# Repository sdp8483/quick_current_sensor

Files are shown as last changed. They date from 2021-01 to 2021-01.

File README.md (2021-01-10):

# Quick Current Sensor

This is a current sensor of various ranges for DC current measurements. The number one goal of this project was to make a set of current sensors only using what I have on hand, no buying anything. Also this has to be a simple design that gets the job done. It is not then best design and will not be the most accurate so it requires characterization before use. I suggest finding a better design with properly selected components, I suggest looking into the INA series of current sense amplifiers from TI that would make a better opamp to use then the old LM358. Again the only goal of this project is to use what I have already and not to waste time searching for the perfect components. Searching for the perfect components and design is what has stalled this project for years. That is just my way of defending the terrible design decisions made here and why you should look somewhere else for a current sensor.

### Calculations
[Google Sheets Link](https://docs.google.com/spreadsheets/d/1N8hUBOZxmFQPPFe9W_K_Z5sfmQMQ_LQjQ09W4D_ssm8/edit?usp=sharing)

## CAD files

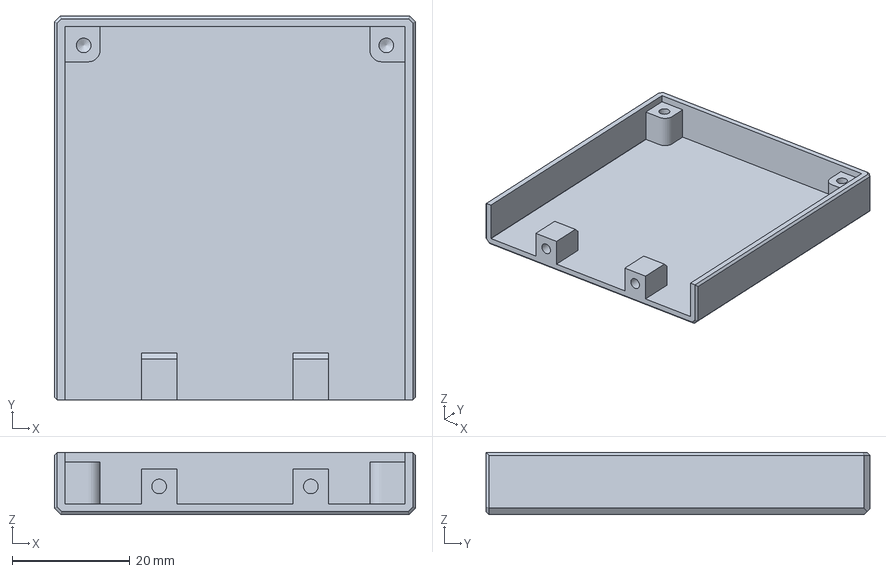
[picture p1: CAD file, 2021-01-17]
enclosure/bottom.amf
61.5 x 65.3 x 10.6 mm

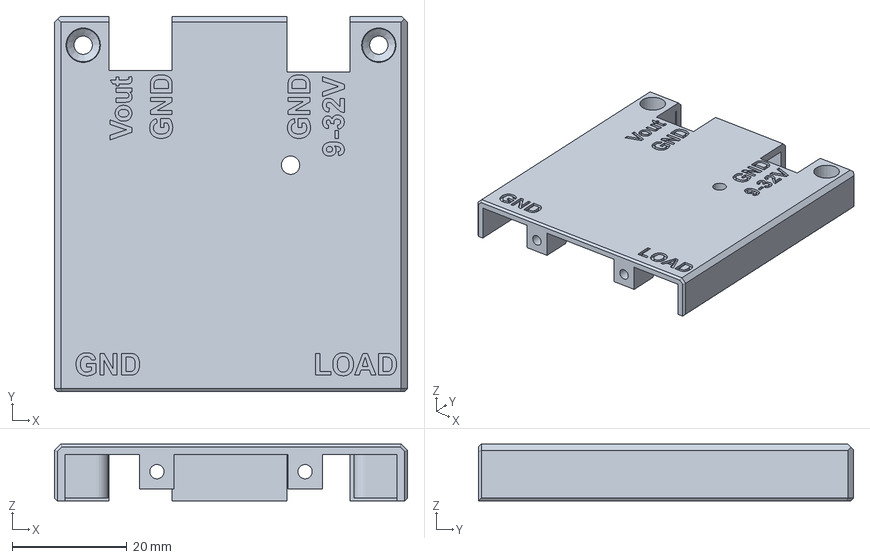
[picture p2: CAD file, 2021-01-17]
enclosure/top.amf
61.5 x 65.3 x 9.90 mm

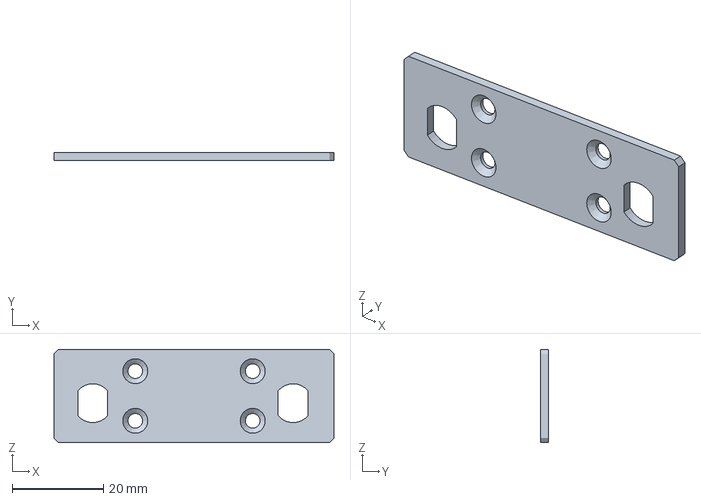
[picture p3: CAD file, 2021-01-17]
enclosure/pannel.amf
61.5 x 1.80 x 20.5 mm

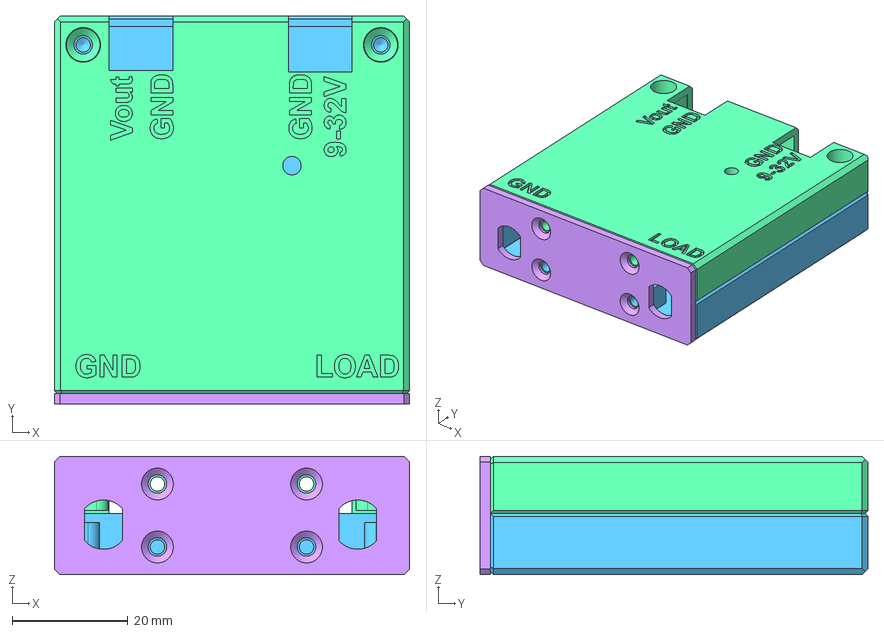
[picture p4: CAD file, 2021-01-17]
enclosure/qcs_enclosure.FCStd
61.5 x 67.1 x 20.5 mm
pannel
enclosure_bottom
enclosure_top

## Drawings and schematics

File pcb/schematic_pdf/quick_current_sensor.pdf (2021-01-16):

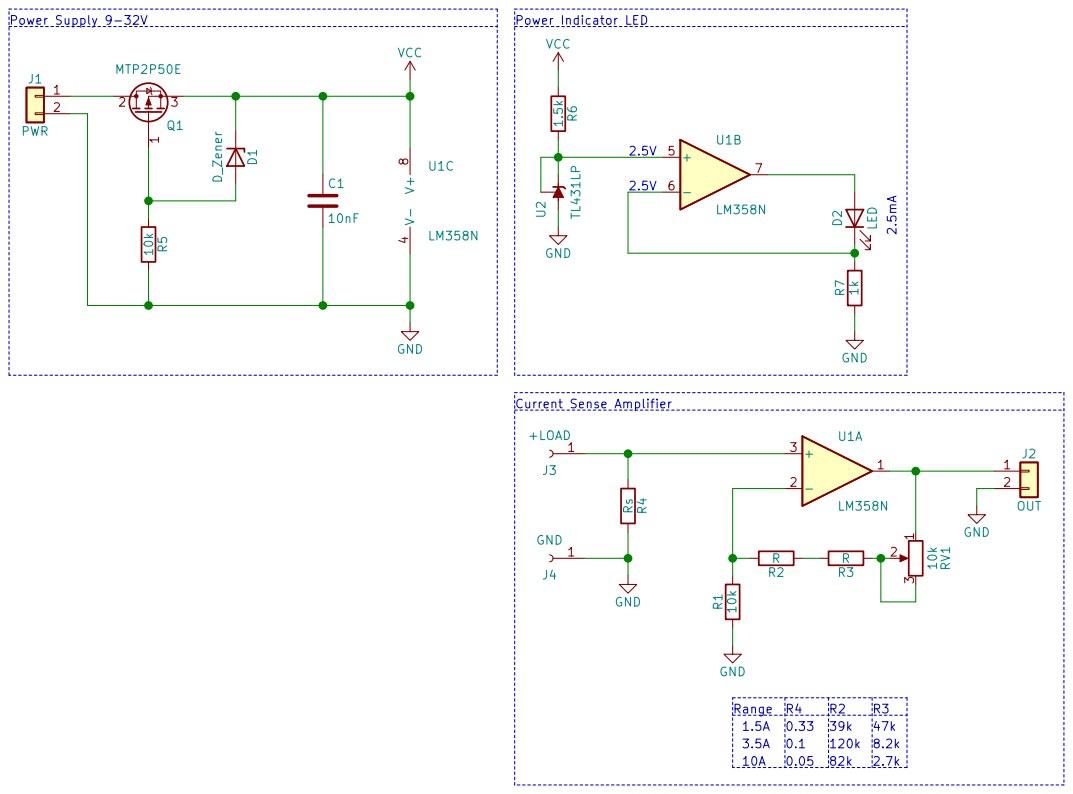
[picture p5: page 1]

R4 | 39k Range R2 | R3
1.5A 3.5A | 0.33 0.05 | 2.7k 8.2k 47k

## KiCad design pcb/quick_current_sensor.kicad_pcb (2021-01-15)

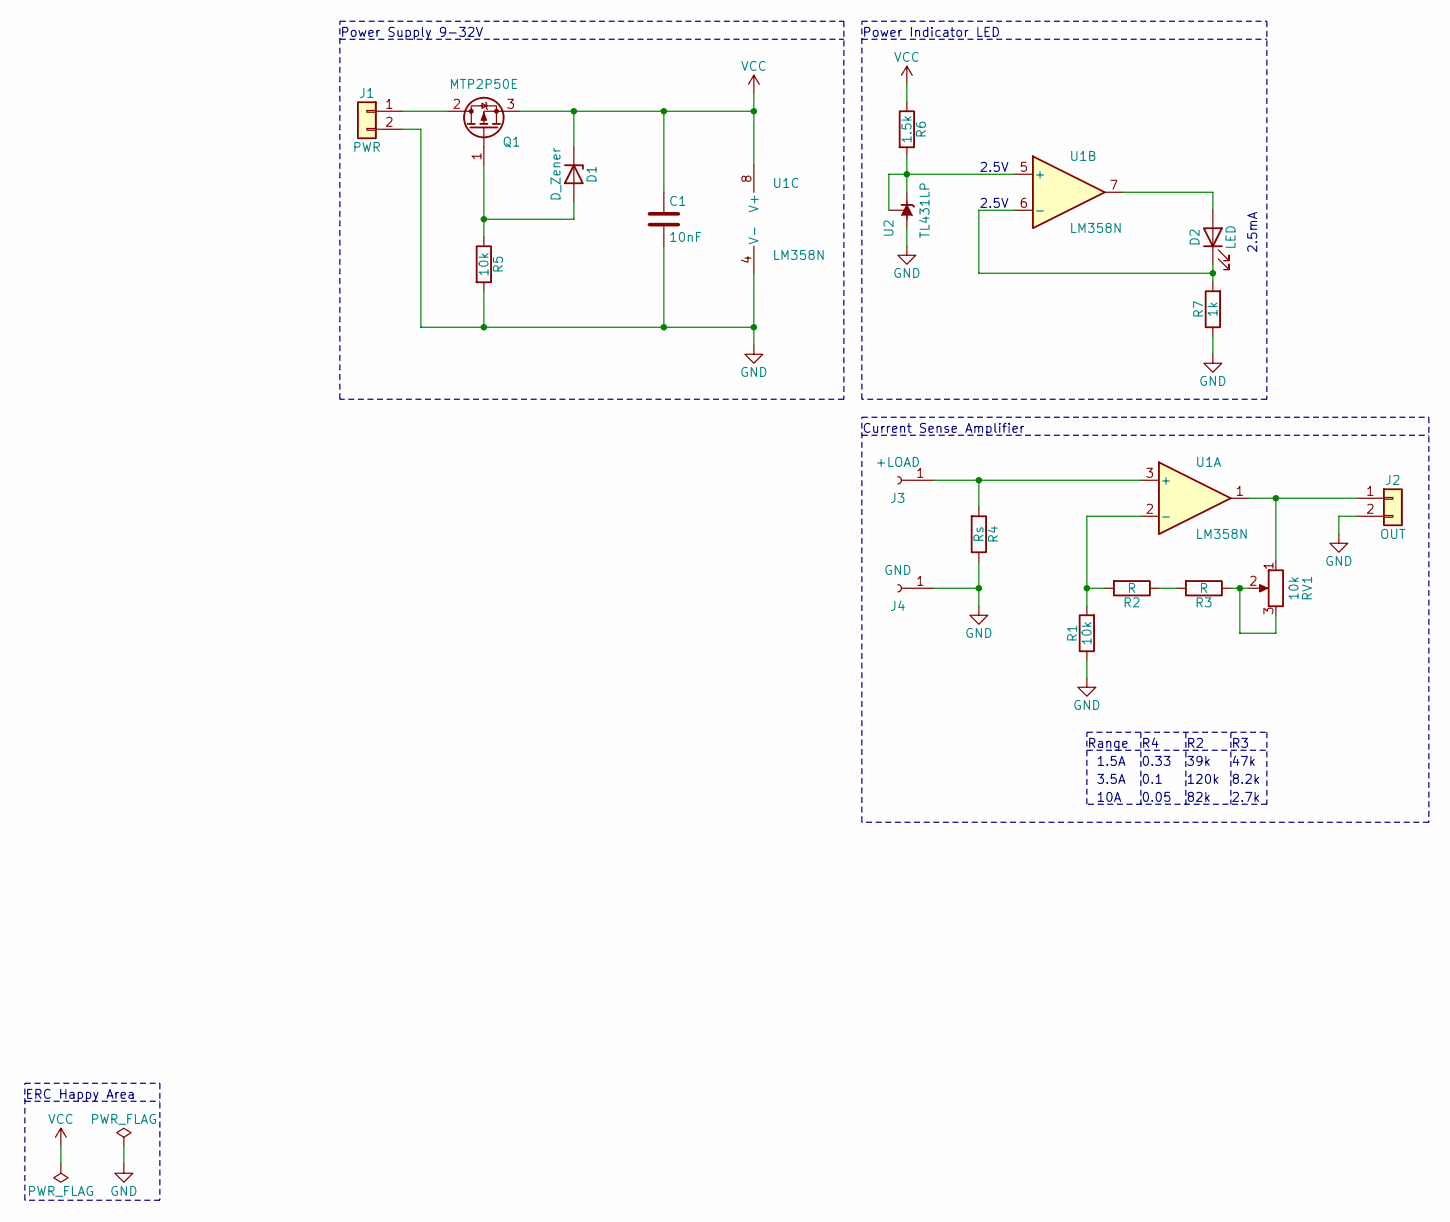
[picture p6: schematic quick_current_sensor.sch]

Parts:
C1: 10nF; C_0805_2012Metric_Pad1.18x1.45mm_HandSolder
D1: D_Zener; Nexperia_BZV55_SOD80C
D2: LED; LED_D3.0mm
J1: PWR; WJ127-5.0-2P
J2: OUT; WJ127-5.0-2P
J3: +LOAD; banana_edge_mount
J4: GND; banana_edge_mount
Q1: MTP2P50E; TO-220-3_Horizontal_TabUp
R1, R5: 10k; R_Axial_DIN0207_L6.3mm_D2.5mm_P10.16mm_Horizontal
R2, R3: R; R_Axial_DIN0207_L6.3mm_D2.5mm_P10.16mm_Horizontal
R4: Rs; RH-10
R6: 1.5k; R_Axial_DIN0207_L6.3mm_D2.5mm_P10.16mm_Horizontal
R7: 1k; R_Axial_DIN0207_L6.3mm_D2.5mm_P10.16mm_Horizontal
RV1: 10k; Potentiometer_Bourns_3006P_Horizontal
U1: LM358N; DIP-8_W7.62mm_LongPads
U2: TL431LP; TO-92_W4.0mm_StaggerEven_Horizontal_FlatSideDown

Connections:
GND: C1.2, J1.2, J2.2, J4.1, R1.1, R4.1, R5.2, R7.1, U1.4 (V-), U2.2 (A)
unnamed: D1.2 (A), Q1.1 (G), R5.1
unnamed: D2.1 (K), R7.2, U1.6 (-)
unnamed: D2.2 (A), U1.7
unnamed: J1.1, Q1.2 (D)
unnamed: J2.1, RV1.1, U1.1
unnamed: J3.1, R4.2, U1.3 (+)
unnamed: R1.2, R2.2, U1.2 (-)
unnamed: R2.1, R3.2
unnamed: R3.1, RV1.2, RV1.3
unnamed: R6.2, U1.5 (+), U2.1 (REF), U2.3 (K)
VCC: C1.1, D1.1 (K), Q1.3 (S), R6.1, U1.8 (V+)

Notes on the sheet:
Range
1.5A
3.5A
10A
0.33
0.1
0.05
39k
120k
82k
47k
8.2k
2.7k
2.5V
2.5mA
Power Supply 9-32V
Power Indicator LED
Current Sense Amplifier
ERC Happy Area

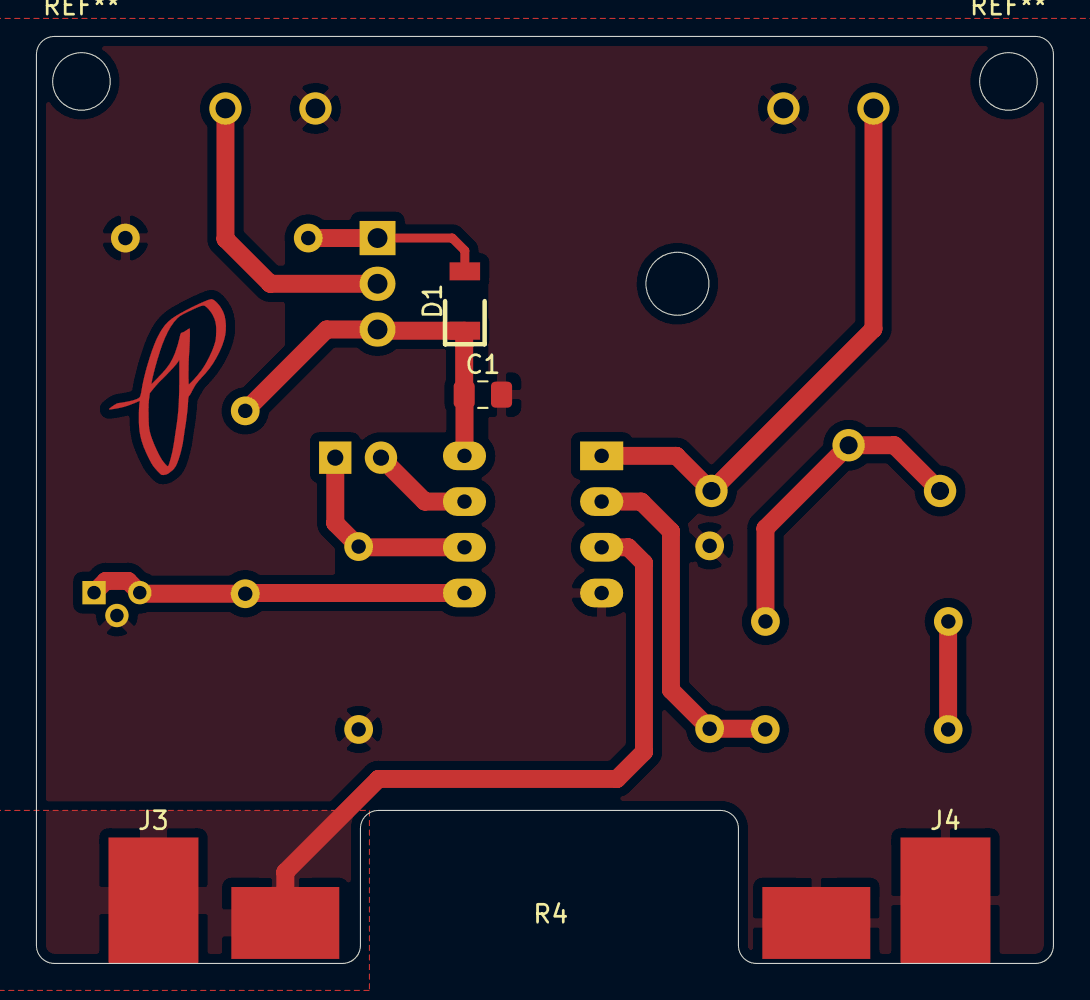
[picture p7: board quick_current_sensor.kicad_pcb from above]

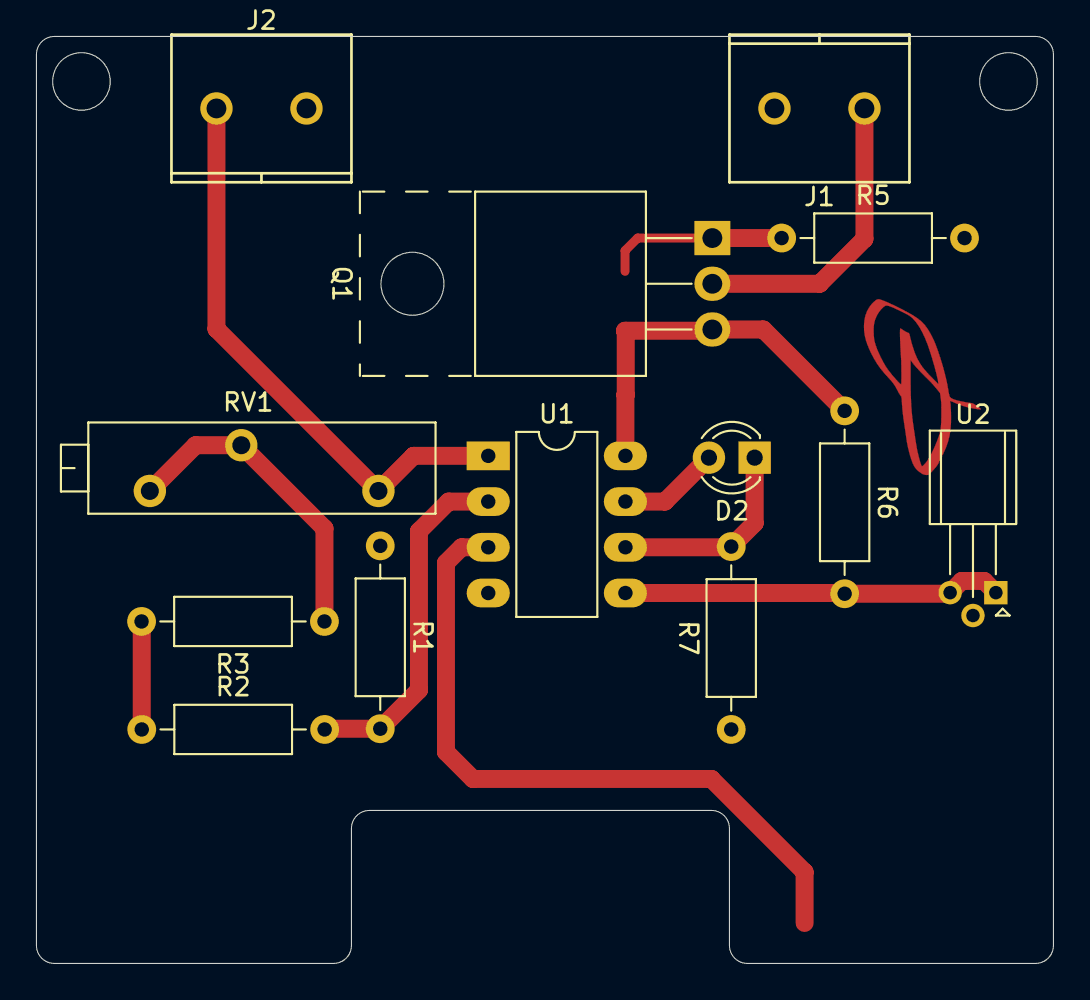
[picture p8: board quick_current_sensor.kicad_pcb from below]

Board: 2 copper layers, 56.5 x 51.5 mm, 18 parts (13 on the bottom side), 12 nets.

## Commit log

2021-01-12 add Rs footprint and 3d model
    [quick_current_sensor.kicad_pcb, quick_current_sensor.sch]
2021-01-13 cleanup and add logo
    [quick_current_sensor.kicad_pcb, quick_current_sensor.sch]
2021-01-13 start enclosure design
2021-01-14 change power and vout to terminal blocks
    [quick_current_sensor.kicad_pcb, quick_current_sensor.sch]
2021-01-14 cleanup, reduce size
    [quick_current_sensor.kicad_pcb, quick_current_sensor.sch]
2021-01-15 updated enclosure for new IO
2021-01-15 added banana cutouts
    [qcs_enclosure.FCStd]
2021-01-15 sink top screw heads
    [qcs_enclosure.FCStd]
2021-01-15 add material around screw holes
    [qcs_enclosure.FCStd]
2021-01-15 generate gerbers
    [quick_current_sensor.kicad_pcb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]
2021-01-15 plot schematic pdf
2021-01-16 generate pcb gcode
2021-01-16 plot pdf
    [quick_current_sensor.kicad_pcb]
2021-01-16 mirror labeling to match PCB
    [qcs_enclosure.FCStd]
2021-01-16 reduce edge chamfer
    [qcs_enclosure.FCStd]
2021-01-16 change font
    [qcs_enclosure.FCStd]
2021-01-16 increase pannel banana hole clearance
    [qcs_enclosure.FCStd]
2021-01-17 export 3d files
    [bottom.amf, pannel.amf, top.amf]
2021-01-24 add jupyter notebooks used to characterize sensors
2021-01-24 brother PT-D600 24mm label
